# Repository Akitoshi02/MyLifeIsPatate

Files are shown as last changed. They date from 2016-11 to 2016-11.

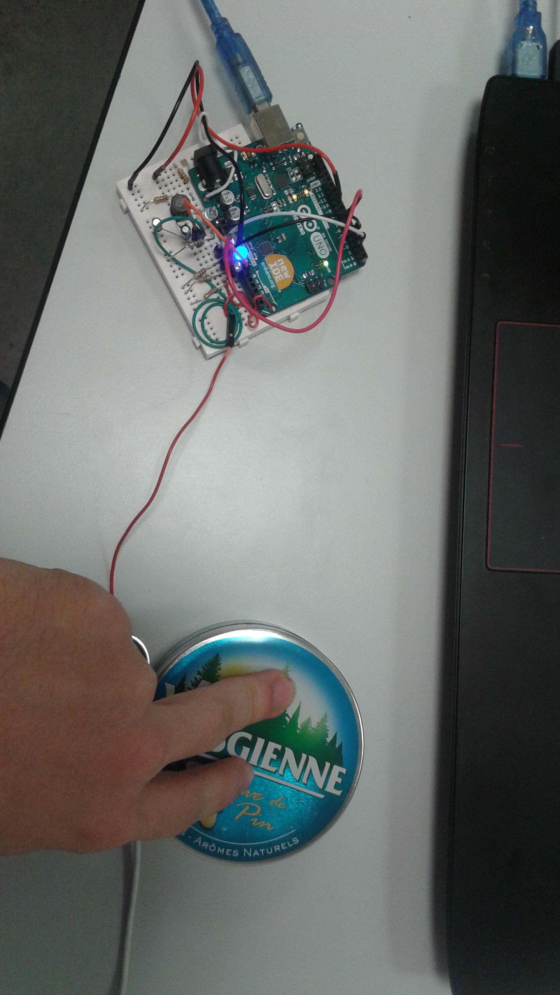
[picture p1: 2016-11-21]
Rapport-PowerPoint-Base de connaissance/Photo Montage/20161121_130452.jpg

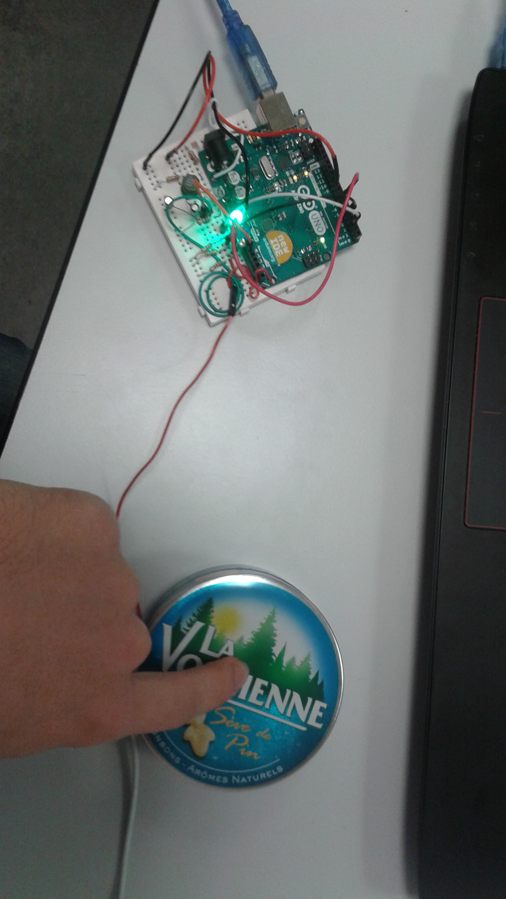
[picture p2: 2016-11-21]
Rapport-PowerPoint-Base de connaissance/Photo Montage/20161121_130448.jpg

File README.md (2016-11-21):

# MyLifeIsPatate

Vous trouverez dans ce repo 4 sous-dossiers
"Code de mesure" qui contient les codes sources Processing (ocilloscope, Graph)

"Code source" qui contient les programmes permettant de générer le signal analogique et
d'écrire les résultats sur le ports série et le programme "main" qui est le code final

"Fritzing" Contient les schémas platine/schématique/PCB du système

"Rapport-PowerPoint-Base de connaissance" Contient des ressources, le rapport et le pdf du rapport

Todo list

- Corriger Rapport - OK
- créer PDF final - OK
- Créer powerpoint - OK
- Code arduino Sensing - OK

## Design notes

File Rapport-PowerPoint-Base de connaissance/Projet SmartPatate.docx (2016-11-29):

14/11/2016

VAUBOURG Mandel

CHAMPAULT Quentin

Exia.Cesi

PROJET SCIENTIFIQUE

SmartPatate

# CONTEXTE DU SUJET

Nous disposons d’une pomme de terre ou un verre d’eau (Nous utiliserons un verre d’eau) comme capteur. Le but est de pouvoir détecter quand une personne touche le verre avec un doigt, deux doigts ou la main complète. Pour ce faire nous disposons de deux expériences à réaliser qui nous permettra de comprendre et d’analyser les interactions physiques de notre montage.

Nous utiliserons une Arduino qui alimentera notre circuit en régime périodique et de récupérer sur son port alogique A0 la tension de sortie, nous avons à notre disposition des programmes Arduino qui permettrons de générer un signal périodique à une fréquence donnée, et d’envoyer les résultats des mesures sur le port Série de l’Arduino. Nous récupérerons ces mesures via le logiciel Processing qui permettra d’afficher le signal mesuré et d’y définir des profils quand on touche avec un doigt, deux doigts ou la main.

Les capteurs capacitifs sont très utiles pour tous domaines d’application ! Car ils permettent la détection de toutes matières organiques (personne, animal, alimentaire, etc…) ou métalliques, ils sont même capables de détecter de façon fiable du verre transparent ou même des fluides. (Plus la constante Diélectrique* du matériau à détecter est grande plus la distance de détection l’est aussi).

Ainsi pour un fluide par exemple, (qui dispose d’une grande constante diélectrique) le capteur capacitif va permettre de contrôler le niveau du liquide. De même le capteur n’a pas besoin de se situer proche du matériau à détecte, il peut aussi y avoir un obstacle devant !

*Substance isolante, capable d'emmagasiner de l'énergie électrostatique. Un diélectrique est caractérisé par sa permittivité ou constante diélectrique. Dans un condensateur le diélectrique est placé entre deux plaques ou feuilles conductrices.

# EXPERIMENTATION

### Expérience 1

Cette première expérience va nous permettre de comprendre le fonctionnement d’un capteur capacitif (ici en régime périodique) en analysant la tension crête à crête quand on touche le verre d’eau ou non.

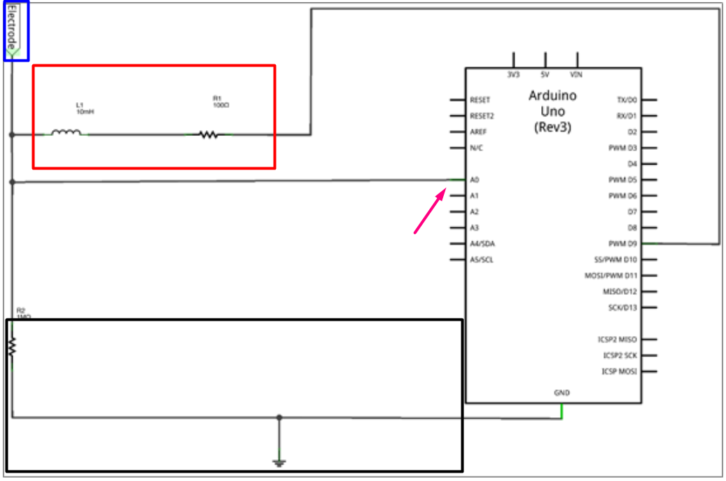
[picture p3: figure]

L’Arduino génère un signal Analogique (les fréquences sont détaillées dans le tableau ci-dessous) envoyé au circuit. La zone rouge est composée d’une résistance R1 (100 Ω) est une bobine L1 (10 mH). Ce montage se comporte comme un filtre passe-Bas, la bobine ne laissant pas passer les Hautes fréquences.

Avec ω=2 πF

La transmittance de ce filtre :

T=(Vs)/(Ve)=(Z_l *Y_l)/((Z_r + Z_l )*Y_l)=1/(1+ R/(j Lω))= 1/(1-j R/(Lω))

Son module :

|T|= √(a^2 + b^2)= √(1^2 +(R/(Lω))^2)

Sa phase :

φ= tan^(-1) b/a= R/(Lω)

Puis la zone bleue qui représente l’électrode (qu’on peut remplacer par un fil). Quand une personne touche le fil elle va se charger, Comme un nombre d’électron s’échappe via l’électrode durant la charge, la tension enregistrée via le PIN A0 (flèche Violette) diminue

U = R x I

La zone en noir représente les points de masses séparés du reste du circuit par une résistance R2 d’une valeur de 1MΩ évitant au courant de s’échapper dans sa quasi-totalité vers la masse.

Fréquence | 500Hz | 1KHz | 10KHZ | 50KHZ | 100KHz | 200KHz | 300KHz | 400KHz | 500KHz | 600KHz
Tension crête à crête pas touché | 5 | 5 | 5 | 5 | 5 | 5 | 3.5 | 1.25 | 1 | 0.8
Tension crête à crête touché | 5 | 5 | 5 | 5 | 5 | 5 | 1.25 | 0.6 | 0.5 | 0.4

De 500 à 200kHz aucun changement ne se passe quand on touche ou non l’électrode (filtre passe-bas), cependant de 300kHz à 600kHz il y a un changement. De plus, plus f augmente plus l’écart se réduit…

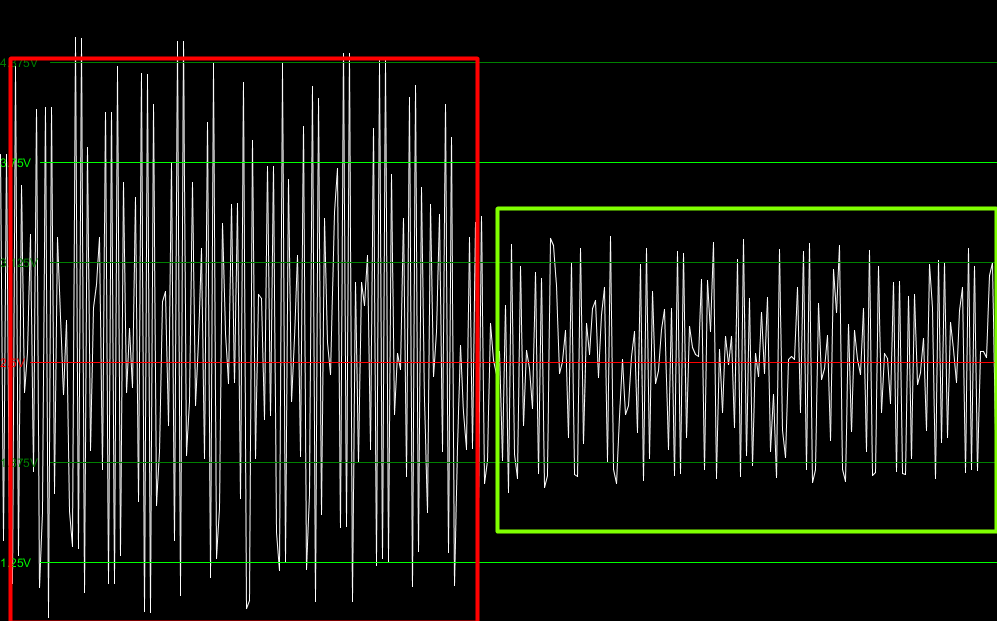
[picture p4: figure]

En rouge quand on ne touche pas l’électrode en vert quand on la touche.

Visualisation des profils (Remplacement de la patate par un verre d’eau)

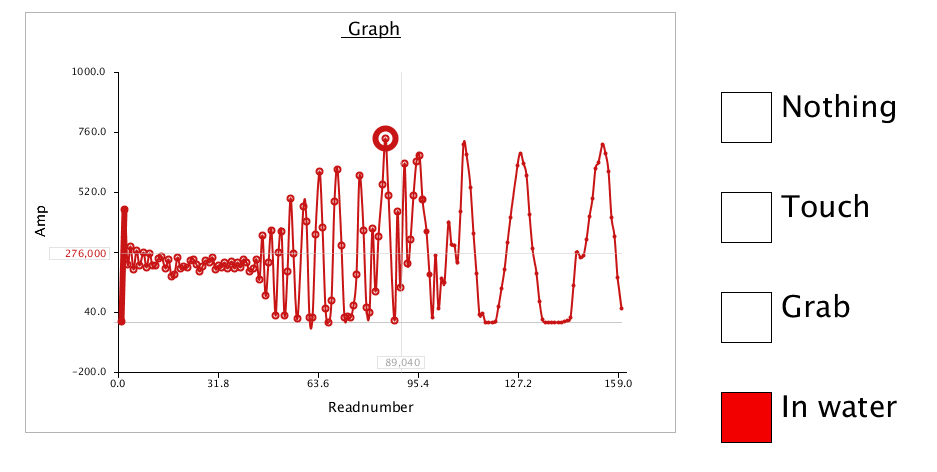
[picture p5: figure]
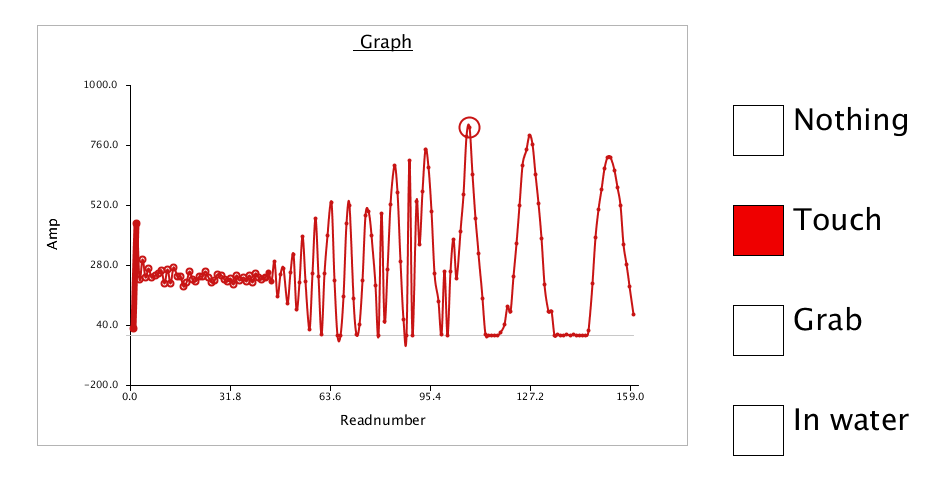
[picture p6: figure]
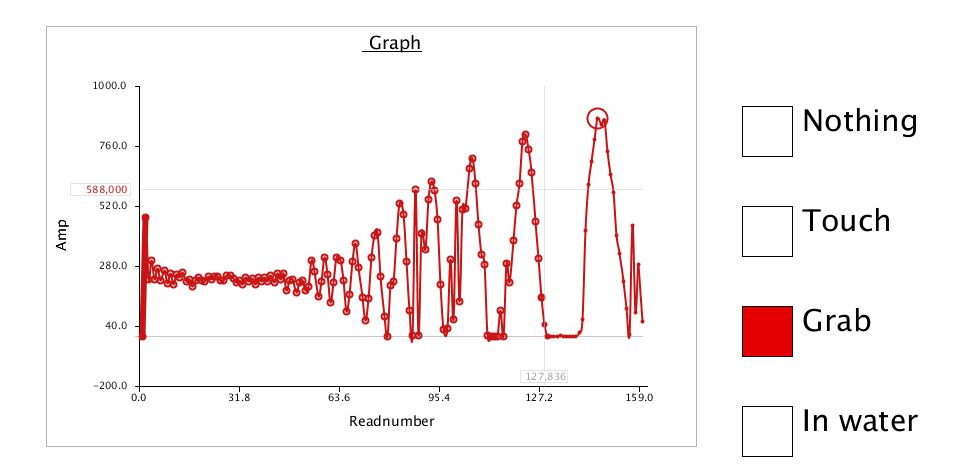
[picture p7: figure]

QUESTION.

Pourquoi parle-t-on de capteur capacitif ? Déduisez-en quel composant le corps humain remplace dans le montage. Pourquoi le signal diminue-t-il ?

Car le matériau qui touchera l’électrode se comportera comme un condensateur, Ainsi notre corps se comporte comme tel.

Avec ces résultats expérimentaux, calculer la capacité de votre corps en fonction du type de contact.

### Expérience 2

Cette seconde expérience sera la base de notre système final. Nous verrons que ce montage est plus performant que le précédent, car il fournis un signal plus lisse

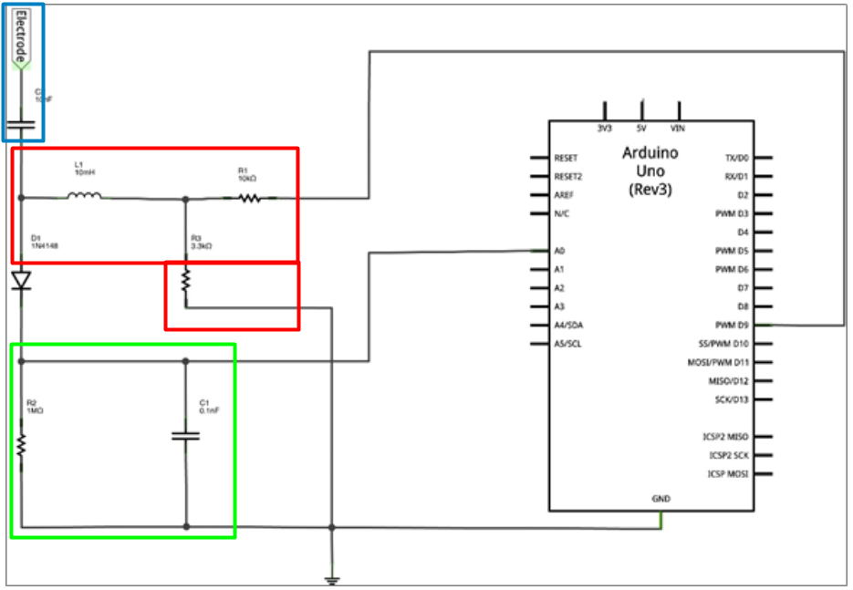
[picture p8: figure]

Nous retrouvons le schémas RL (zone rouge) Passe-Bas avec une résistance en parallèle qui relie la masse, cela permet d’enlevé les signaux parasites…

En bleu l’électrode cependant elle est en série avec un condensateur C1 de 10 nF. Ce condensateur en série avec l’électrode qui est au contact avec une personne est un condensateur donc deux condensateurs en série. Cela permet d’augmenter la capacité de la personne et donc de rajouté une nette différence entre les profils (dans l’eau, touché, attrapé)

En vert nous avons un circuit RC parallèle que se comporte comme un filtre, en basse fréquence le condensateur va agir comme un circuit ouvert, ainsi les hautes fréquences sont éliminées à la masse.

A0 est aux bornes de la zone rouge qui filtre une première fois les hautes fréquences, et la zone vertes qui les élimines davantage. Nous allons voir ainsi que la courbe obtenue avec Processing est nettement plus lissée qu’avec la première expérience.

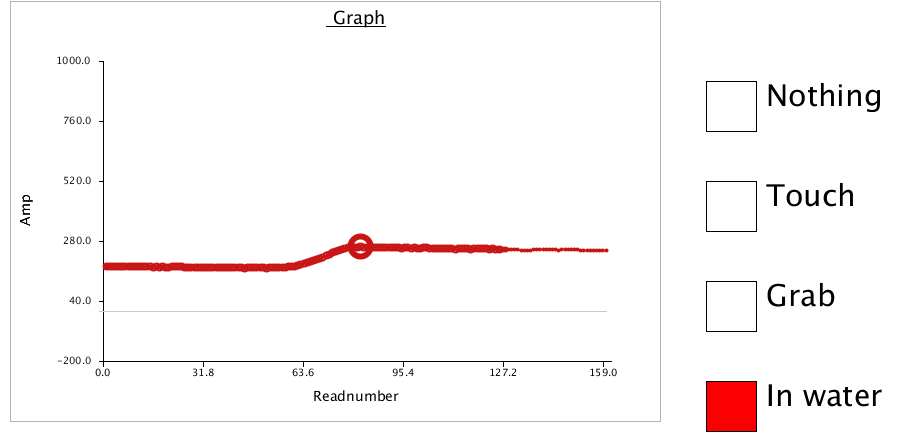
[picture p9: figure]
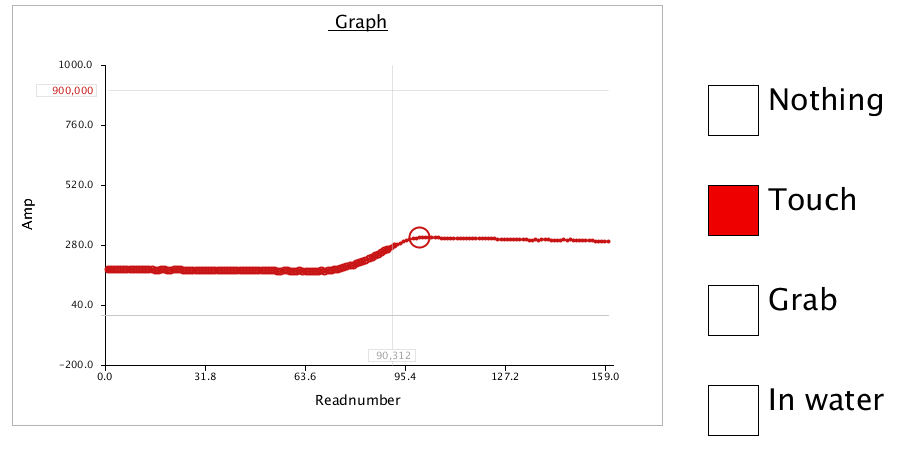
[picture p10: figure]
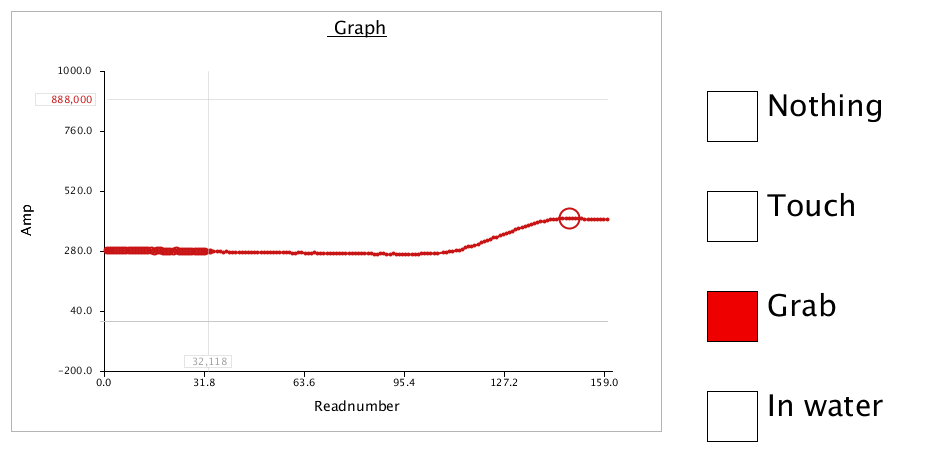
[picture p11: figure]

# EXPLICATION CIRCUIT/COMPOSANTS

Ce circuit est une capteur capacitif, relié à une arduino qui permettra de fournir un courant alternatif PWM (broche 9), et de mesurer la tension de sortie via A0 nous avons déjà précédemment expliqué le fonctionnement de chaque zone du circuit mais pas composant par composant.

Nous avons donc un circuit sous régime alternatif, ce circuit dispose d’un montage RL, RC, d’une diode et d’une électrode en série avec un condensateur.

Dans la zone rouge nous trouvons une bobine et une résistance en série, ce montage est un filtre. En effet la bobine ne laisse passer que les Basses fréquences et élimine les hautes (via la résistance R3).

En bleu nous avons un condensateur en série avec l’électrode, Nous savons grâce à l’expérience 1 que le corps humain agit comme un condensateur nous pouvons créer ce schéma équivalent :

Quand une personne touche le verre d’eau (ou la pomme de terre) il augmente la capacité sellons comment il touche (un doigt deux doigts ou la main) l’électrode, ce changement de capacité vas changer la tension crête à crête (comme vue dans l’expérience 1), les électrons vont aller vers l’électrode pour charger le condensateur.

La LED quant à elle permet d’éviter un retour de courant dans la zone rouge, (qui via R3 est relié à la masse donc circuit fermé) en effet le condensateur de la zone verte vas se décharger, la LED évite que le courant s’échappe via R3

# PRESENTATION PROTOTYPE

Schémas électriques :

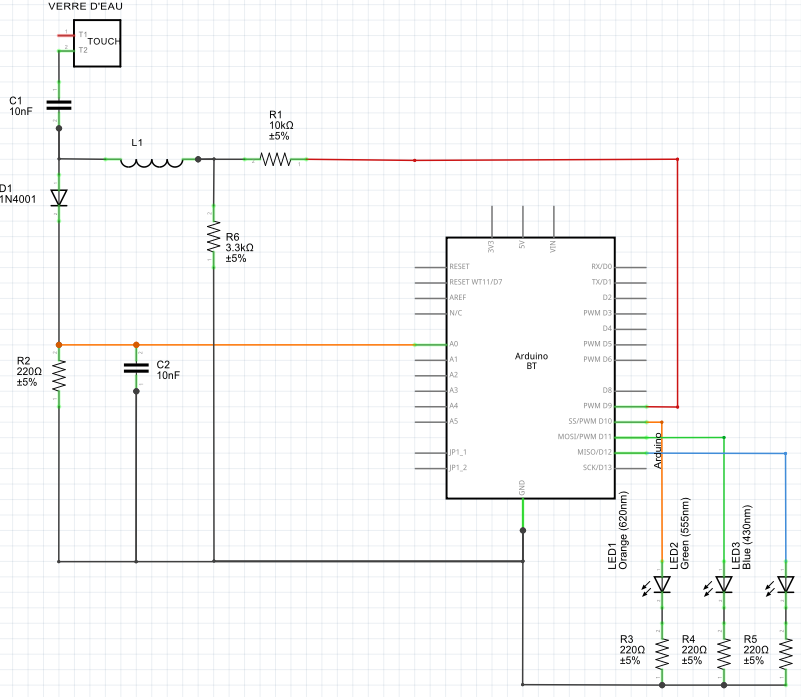
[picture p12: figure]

Réalisation :

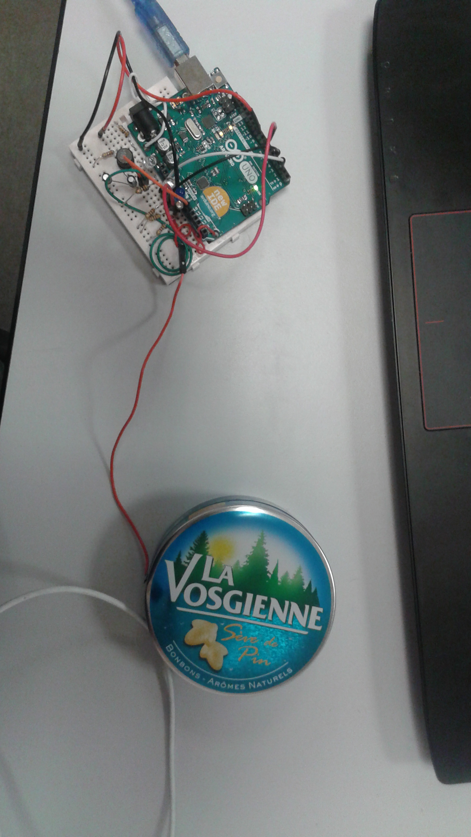
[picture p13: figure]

La boite métallique est plus stable que le verre d’eau…

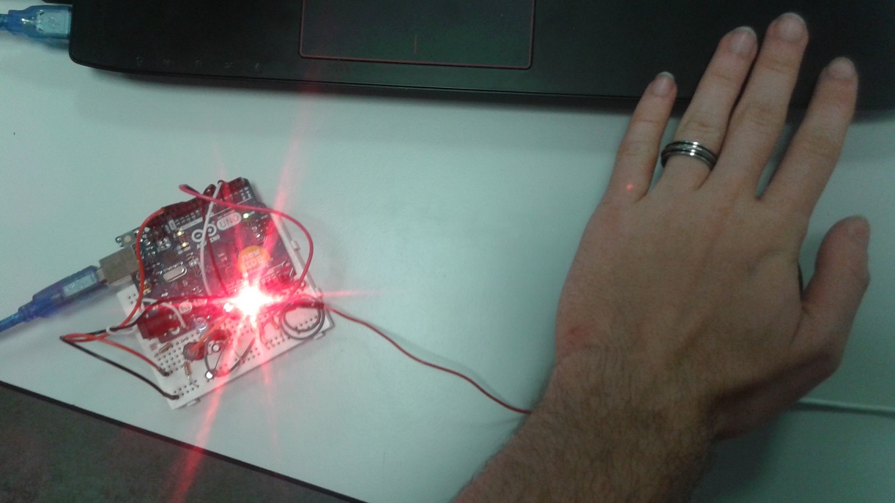
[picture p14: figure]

### Partie Fritzing

Arduino

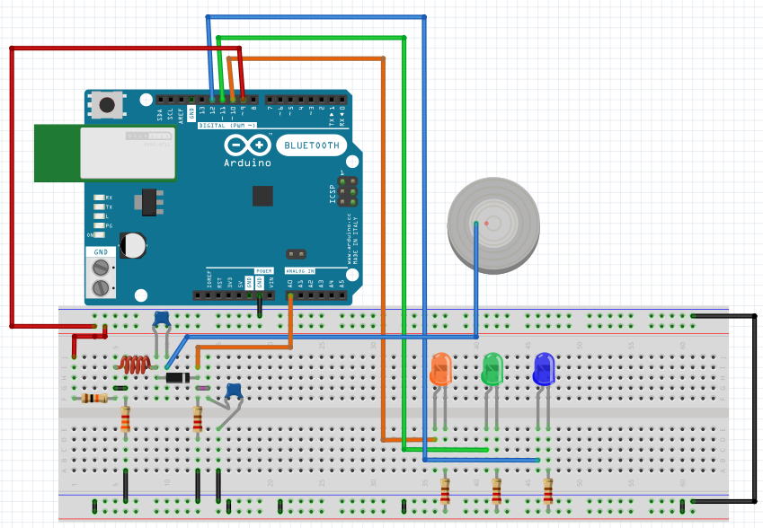
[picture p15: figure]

Schématique

Circuit imprimé

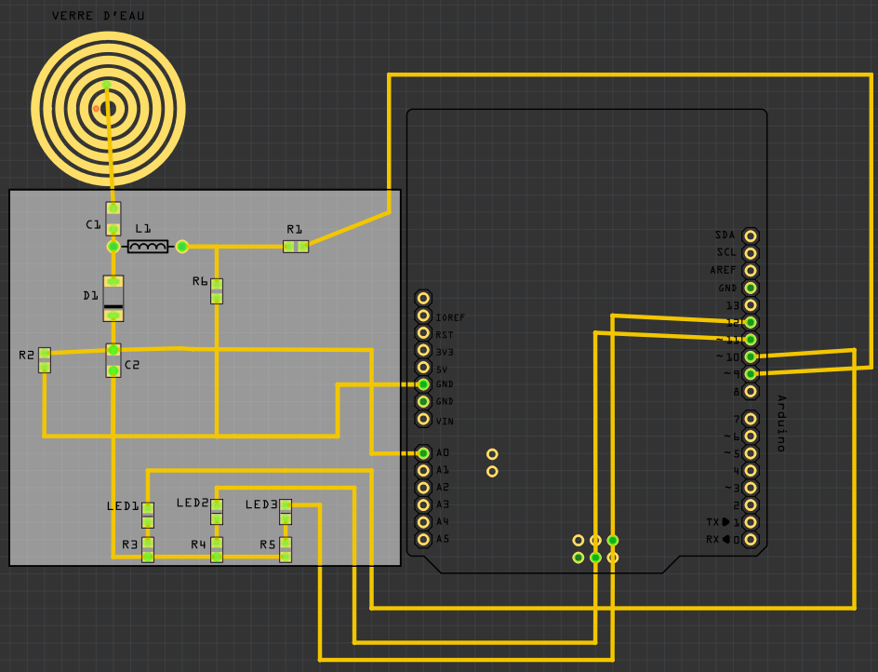
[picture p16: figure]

Code

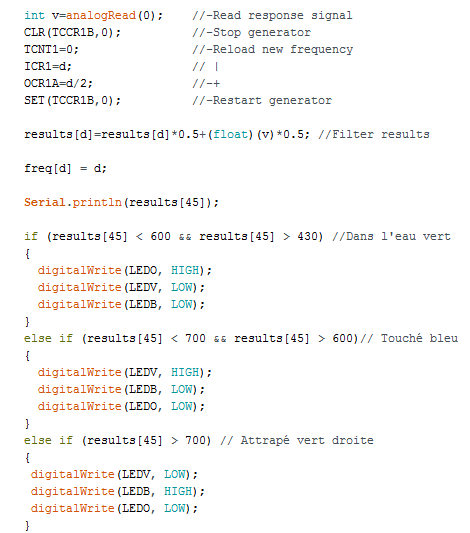
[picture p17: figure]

Voici la partie importante du code… la première ligne permet de lire le pin A0 qui permet de récupérer la tension de sortie. Les ligne du dessous permettent de générer une fréquence - nous sommes dans une boucle for qui bouclera 160 fois – ainsi nous générons une plage de fréquence. Enfin ce qui nous permettra de détecter les différents touché est le tableau results[] qui contient les valeur de v pour chaque fréquence. Nous avons choisi la 45ème fréquences car elle offrait un bon compromis entre amplitude entre chaque touchés et la sensibilité du capteur. La structure conditionnelle permettra d’allumer les LED sellons la plage de valeur dans laquelle on est…

# BILAN PROJET

Ce projet nous a permis de réellement voir le comportement des composants étudiés durant nos PROSIT (Condensateur, Bobine).

Nous n’avions pas l’ensemble des composants pour effectuer les expériences, ce qui nous a retardé cependant nous avons créé un capteur capacitif d’une autre manière (sans avoir besoin d’un régime alternatif et bobine/condensateur)

Nous avons réussi les montages des expériences, expliquer les phénomènes rencontrés le comportement des composants, ainsi que leur comportement dans un ensemble.

Nous n’arrivons cependant pas à avoir la valeur de la capacité de la personne quand elle touche l’électrode…

VAUBOURG Mandel PROJET SCIENTIFIQUE 14/11/2016 CHAMPAULT Quentin SmartPatate 16/11/2016

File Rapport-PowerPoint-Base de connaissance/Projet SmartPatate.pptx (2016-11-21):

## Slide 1

PROJET SCIENTIFIQUE
Smart Patate

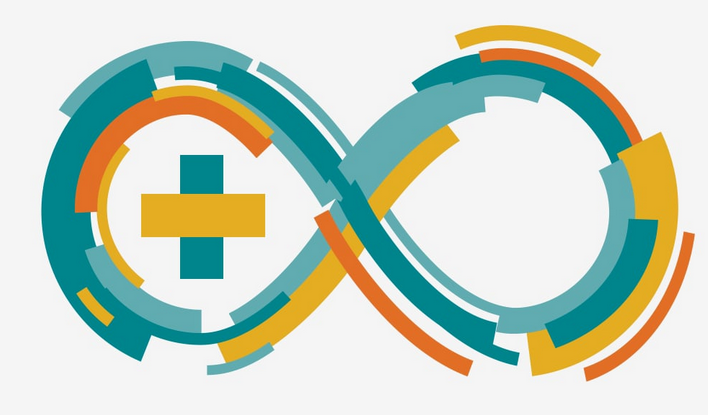
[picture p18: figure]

Exia.Cesi
2016-2017

VAUBOURG Mandel
CHAMPAULT Quentin

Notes: Début diapo attendre le lancement par le jury

## SOMMAIRE

- Contexte Du Projet
- Expérimentation
- Explication circuit/Composant
- Présentation Prototype
- Bilan Projet

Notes: Mandel présente le sommaire

## Contexte Du Projet

- Présentation du projet
- Utilisation des capteurs capacitif

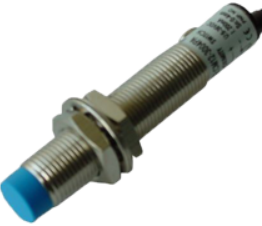
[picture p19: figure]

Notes: Quentin : Présentation projet
Mandel : L’utilisation des capteur

## Expérimentation Expérience 1


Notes: Quentin :
Zone rouge = filtre passe-bas
zone bleu = l’électrode capteur capacitif/condensateur
Flèche rose = Pin A0 on récupère le le signal analogique

L’arduino génère un signal analogique à une fréquence donnée via le port PWM 9

PWM = Pulse With Modulation = génère un signal analogique via un quartz

## Expérimentation Expérience 1

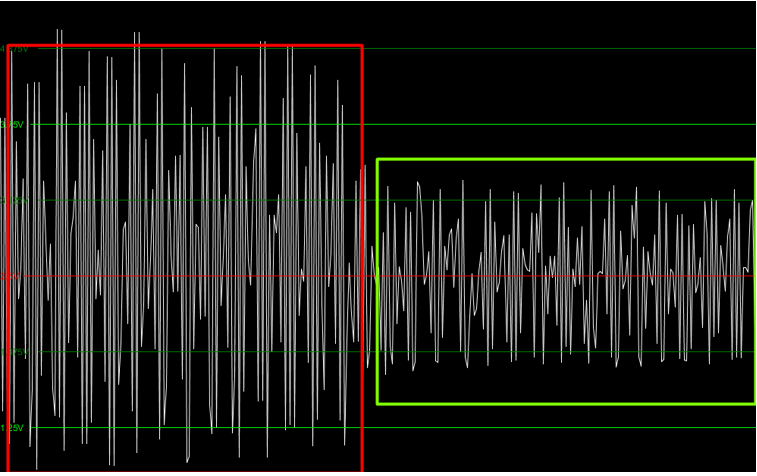
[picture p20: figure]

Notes: Quentin :
Le tableau en basse fréquence 500Hz à 200KHz pas de changement
On Haute fréquence ya atténuation du signal car filtre passe-bas

La zone rouge = quand on touche pas
La zone verte = quand on touche

## Expérimentation Expérience 2


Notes: Mandel explique

## Expérimentation Expérience 2


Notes: Mandel explique

## Explication circuit/composant


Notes: Mandel explique

## Présentation Prototype

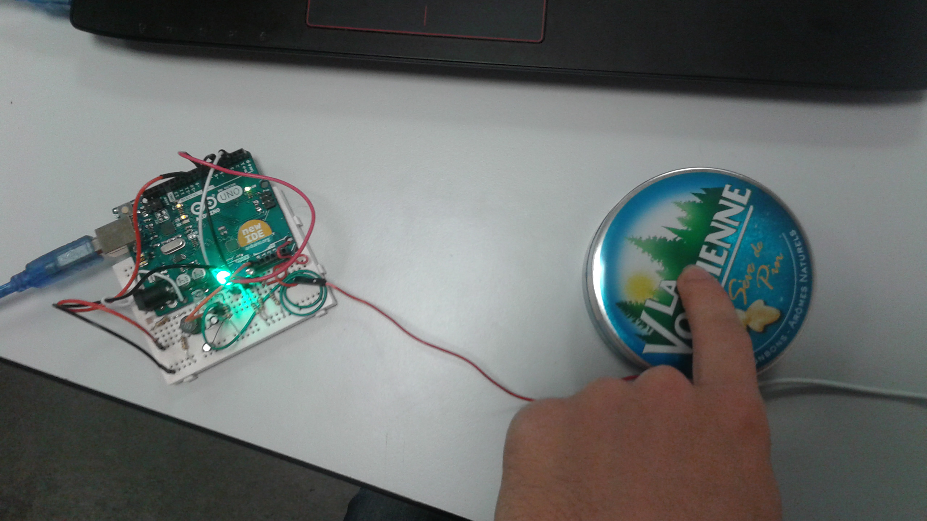
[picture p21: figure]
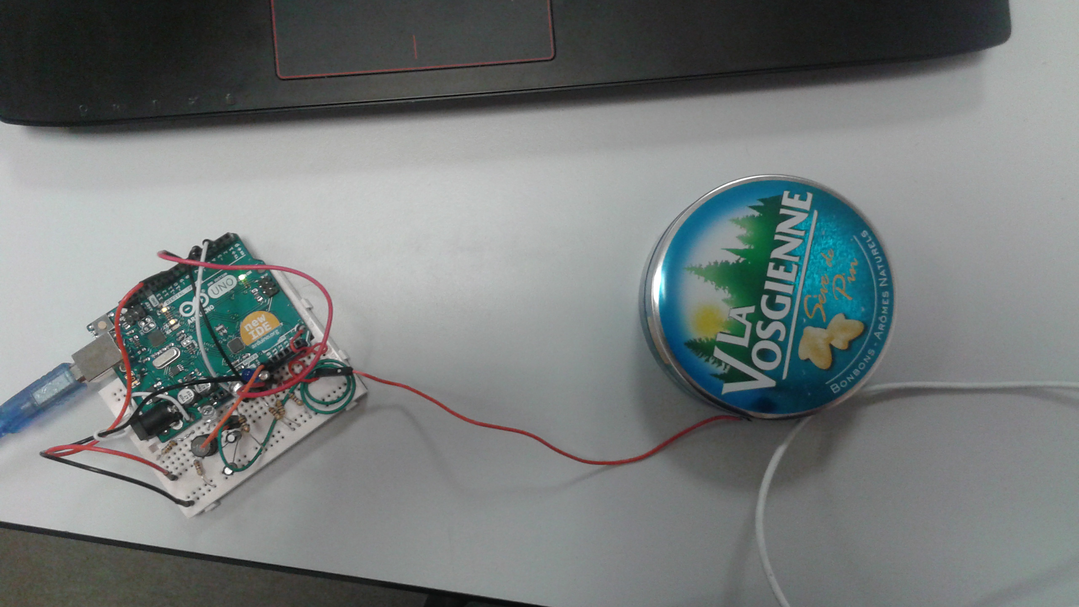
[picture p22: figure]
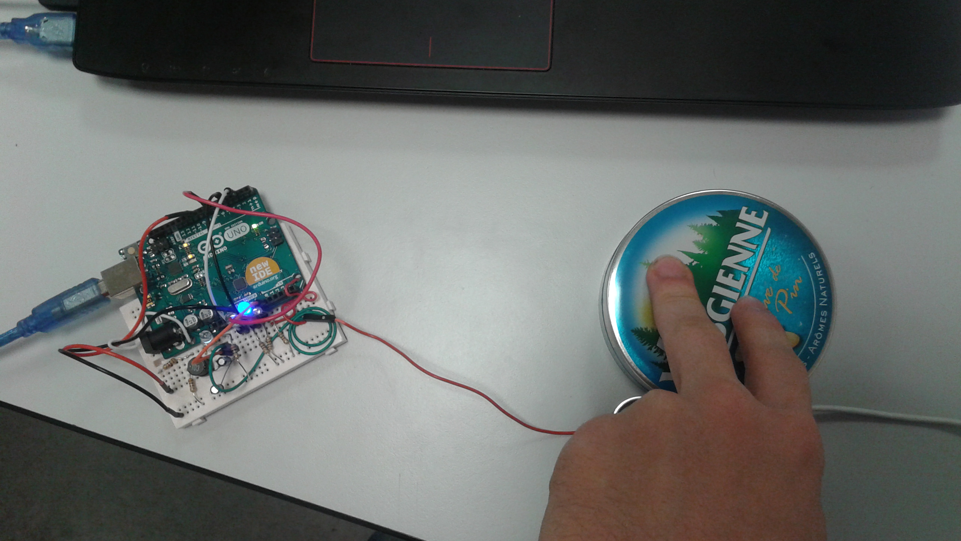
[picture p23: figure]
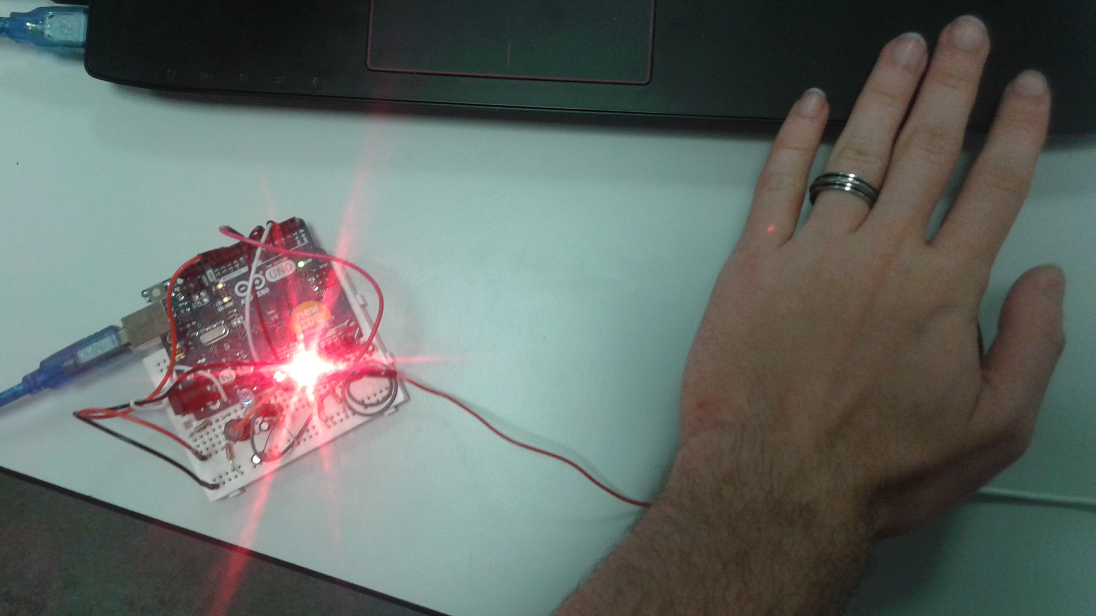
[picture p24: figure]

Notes: Quentin explique

## Bilan Projet

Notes: Au choix on prend la parole

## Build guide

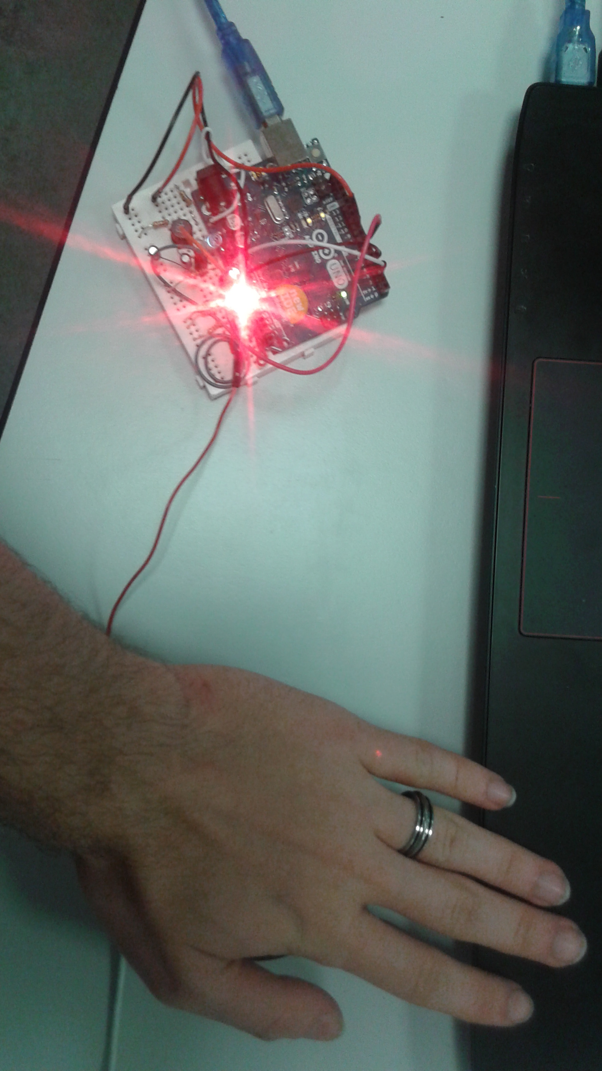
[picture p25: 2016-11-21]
Rapport-PowerPoint-Base de connaissance/Photo Montage/20161121_130456.jpg

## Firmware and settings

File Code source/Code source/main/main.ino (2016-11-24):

   

   
   //****************************************************************************************
// Illutron take on Disney style capacitive touch sensor using only passives and Arduino
// Dzl 2012
//****************************************************************************************


//                              10n
// PIN 9 --[10k]-+-----10mH---+--||-- OBJECT
//               |            |
//              3.3k          |
//               |            V 1N4148 diode
//              GND           |
//                            |
//Analog 0 ---+------+--------+
//            |      |
//          100pf   1MOmhm
//            |      |
//           GND    GND



#define SET(x,y) (x |=(1<<y))				//-Bit set/clear macros
#define CLR(x,y) (x &= (~(1<<y)))       		// |
#define CHK(x,y) (x & (1<<y))           		// |
#define TOG(x,y) (x^=(1<<y))            		//-+



#define N 160  //How many frequencies

float results[N];            //-Filtered result buffer
float freq[N];            //-Filtered result buffer
int sizeOfArray = N;

 
//Définition des ports de sortie des couleurs led

const int LEDO = 2; 
const int LEDV = 4; 
const int LEDB = 7;  
   

void setup()
{
  
  
  TCCR1A=0b10000010;        //-Set up frequency generator
  TCCR1B=0b00011001;        //-+
  ICR1=110;
  OCR1A=55;
  //Led en OUTPUT
	pinMode(LEDO, OUTPUT);
	pinMode(LEDV, OUTPUT);
	pinMode(LEDB, OUTPUT);
	
  pinMode(9,OUTPUT);        //-Signal generator pin
  pinMode(8,OUTPUT);        //-Sync (test) pin

  Serial.begin(115200);

  for(int i=0;i<N;i++)      //-Preset results
    results[i]=0;         //-+
}

void loop()
{
       digitalWrite(LEDO, LOW);
      digitalWrite(LEDV, LOW);
      digitalWrite(LEDB, LOW);
  unsigned int d;

  int counter = 0;
  for(unsigned int d=0;d<N;d++)
  {

	
    int v=analogRead(0);    //-Read response signal
    CLR(TCCR1B,0);          //-Stop generator
    TCNT1=0;                //-Reload new frequency
    ICR1=d;                 // |
    OCR1A=d/2;              //-+
    SET(TCCR1B,0);          //-Restart generator

    results[d]=results[d]*0.5+(float)(v)*0.5; //Filter results
   
    freq[d] = d;
  
    Serial.println(results[45]);

    if (results[45] <= 640 && results[45] > 500) //Dans l'eau vert
    {
      digitalWrite(LEDO, HIGH);
      digitalWrite(LEDV, LOW);
      digitalWrite(LEDB, LOW);
    }
    else if (results[45] <= 710 && results[45] > 645)// Touché bleu
    {
      digitalWrite(LEDV, HIGH);
      digitalWrite(LEDB, LOW);
      digitalWrite(LEDO, LOW);
    }
    else if (results[45] > 715) // Attrapé vert droite
    {
     digitalWrite(LEDV, LOW);
     digitalWrite(LEDB, HIGH);
     digitalWrite(LEDO, LOW);
    }

 //   plot(v,0);              //-Display
 //   plot(results[d],1);
  // delayMicroseconds(1);

  
  }


//PlottArray(1,freq,results); //écrit les valeurs sur le port data
 

  TOG(PORTB,0);            //-Toggle pin 8 after each sweep (good for scope)
}
   

   
    
 

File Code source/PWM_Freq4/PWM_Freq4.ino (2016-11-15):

//****************************************************************************************
// PWM Square Wave Generator
// VLO 2013-2014
//****************************************************************************************


const int outPin = 9; // output pin
const float maxFreq = 16000000; //max freq supported by Arduino (16MHz)

void setup()
{

  Serial.begin(115200); //for sending A0 pin values
  
  pinMode(outPin,OUTPUT);        //Signal generator pin
  
  setFrequency(300000); //generate a square wave (in this case at 1000Hz)
  
  //for test
  //Serial.println();
  //Serial.println(ICR1);
  //Serial.println(TCCR1B);
}

void loop()
{


  int val = analogRead(0);   
  Serial.println(val);                                           
  Serial.write( 0xff );                                                         
  Serial.write( (val >> 8) & 0xff );                                            
  Serial.write( val & 0xff );
 
}

//set frequency (Hz)
//min frequency: 0.24 Hz
//max frequency: 8MHz
void setFrequency(float frequency)
{
 
  if(frequency >=0.24 || frequency <=8000000)
  {
    
    TCCR1A=0b10000010;        // Set up frequency generator, mode 14 (Fast PWM)
    //WGM11 = 1, COM1A1 = 1
    //Fast PWM: TOP=ICR1, update of OCR1x=BOTTOM, TOV1 Flag Set on TOP
    
  
    unsigned int v=0;
    int indscale=0;
    float prescale[] = {1.0,8.0,64.0,256.0,1024.0};
    float period=1/frequency;
    
    while(v==0)
    {
      float curfreq=maxFreq/prescale[indscale];
      float tickperiod=1/curfreq;
      float nbtick=period/tickperiod;
     
      if(nbtick>65535)
      {
        indscale=indscale+1;
      }
      else
      {
        v=nbtick;
      }

    }
    
    int c=prescale[indscale];
    
     switch (c) {
      
         case 1: TCCR1B=0b00011001; break;
         case 8: TCCR1B=0b00011010; break;
         case 64: TCCR1B=0b00011011; break;
         case 256: TCCR1B=0b00011100; break;
         case 1024: TCCR1B=0b00011101; break;
         default: TCCR1B=0b00011000;
     }
    
    //WGM12 = 1, WGM13 = 1
    
    //three last bit of TCCR1B:    CS12   CS11   CS10
    // 0: no clock (timer stopped)  0      0      0
    // clk/1: no prescaling         0      0      1 
    // clk/8                        0      1      0
    // clk/64                       0      1      1
    // clk/256                      1      0      0
    // clk/1024                     1      0      1

    
    ICR1=v; //pulse duration = ICR1 value x time per counter tick
    
    //for 16Mhz (chip frequency)
    //Prescale	Time per counter tick
    //1	        0.0625 uS
    //8	        0.5 uS
    //64	4 uS
    //256	16 uS
    //1024	64uS
    
    OCR1A=v/2; //Output Compare Register //low state

  }
  
  
}

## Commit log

2016-11-14 Add Project .ino
    Ajout du projet arduino
2016-11-15 Ajout des Photos
2016-11-17 add Fritzing
    [MyLifeIsPatate.fzz]
2016-11-17 add Friting
    [MyLifeIsPatate.fzz]
2016-11-17 del redondance
    [MyLifeIsPatate.fzz]
2016-11-17 save Fritzing
    [MyLifeIsPatate.fzz]
2016-11-17 Fritzing FINI
    [MyLifeIsPatate.fzz]
2016-11-18 Start PowerPoint
2016-11-20 Ajout commentaire powerpoint
2016-11-20 ajout prise en compte led
2016-11-20 modif correction
    [MyLifeIsPatate.fzz]
2016-11-20 edit ardui Sensing for led + pdf + rapport
2016-11-21 modif powerpoint
2016-11-21 modif code arduino
